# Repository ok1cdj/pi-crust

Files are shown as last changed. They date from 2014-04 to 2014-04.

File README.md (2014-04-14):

Pi Crust
========

This is a PCB that brings sanity to Raspberry Pi headers.

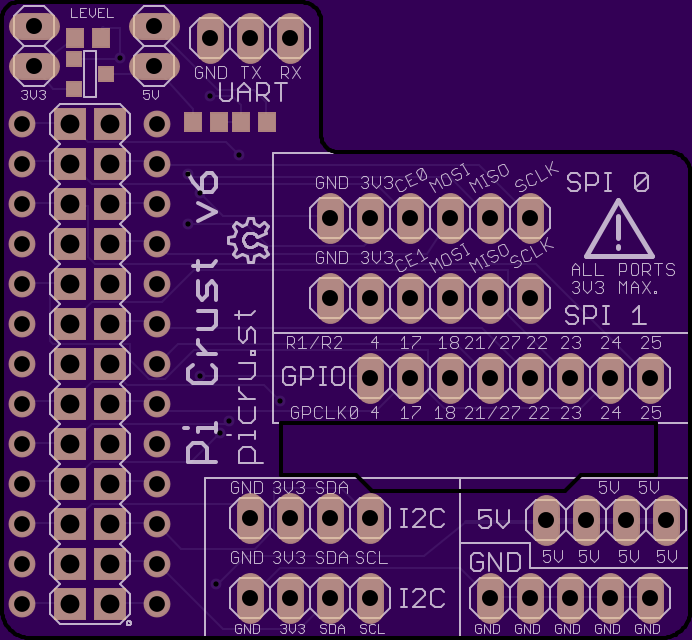
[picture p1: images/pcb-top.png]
Pi Crust PCB Layout


See [http://picru.st](http://picru.st) for more.

Features
--------

*   Really compact - sits *inside* the surface area of the Raspberry Pi and adds less than 2mm to the height. If you have a case for your Raspberry Pi, this board should fit inside it.
*   Pins are grouped together: GPIO, I2C, SPI, UART and power.
*   Every pin is clearly labelled added labels for RPi revision 1 and 2.
*   Connections: 2 x SPI, 2 x I2C, 1 x UART, 8 x GPIO
*   Added bidirectional 2 ports level converter
*   Uses female headers instead of male headers - you can poke jumpers right in.
*   Lots of GND and 5V pins - you need those guys a lot. These pins are duplicated where it makes sense (e.g. within the UART, I2C and SPI groups).
*   All thru-hole components - you can solder it yourself.
*   Cheapety cheapy cheap.
*   Open source hardware.
*   [More photos here](http://todayimade.co/items/joe-walnes-made-a-tiny-breakout-board-for-raspberry-pi)

See [http://picru.st](http://picru.st) for more.

Bitdeli Badge (https://bitdeli.com/free "Bitdeli Badge")

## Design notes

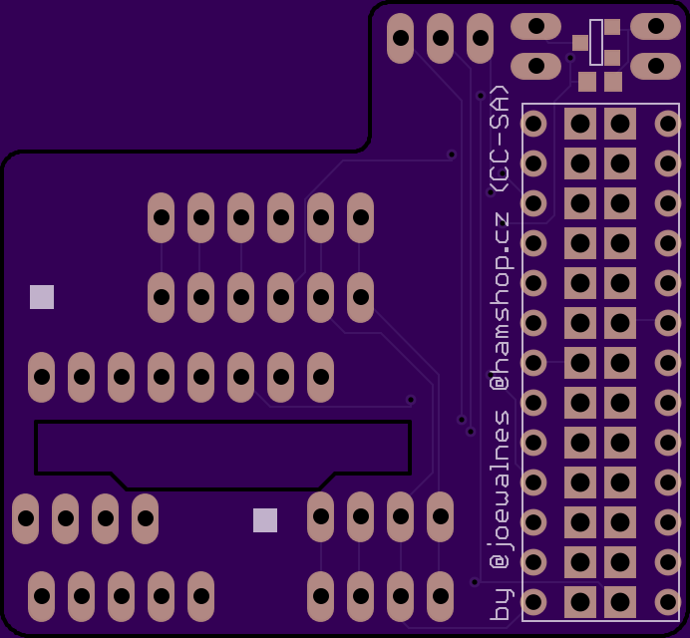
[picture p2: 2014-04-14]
images/pcb-bottom.png

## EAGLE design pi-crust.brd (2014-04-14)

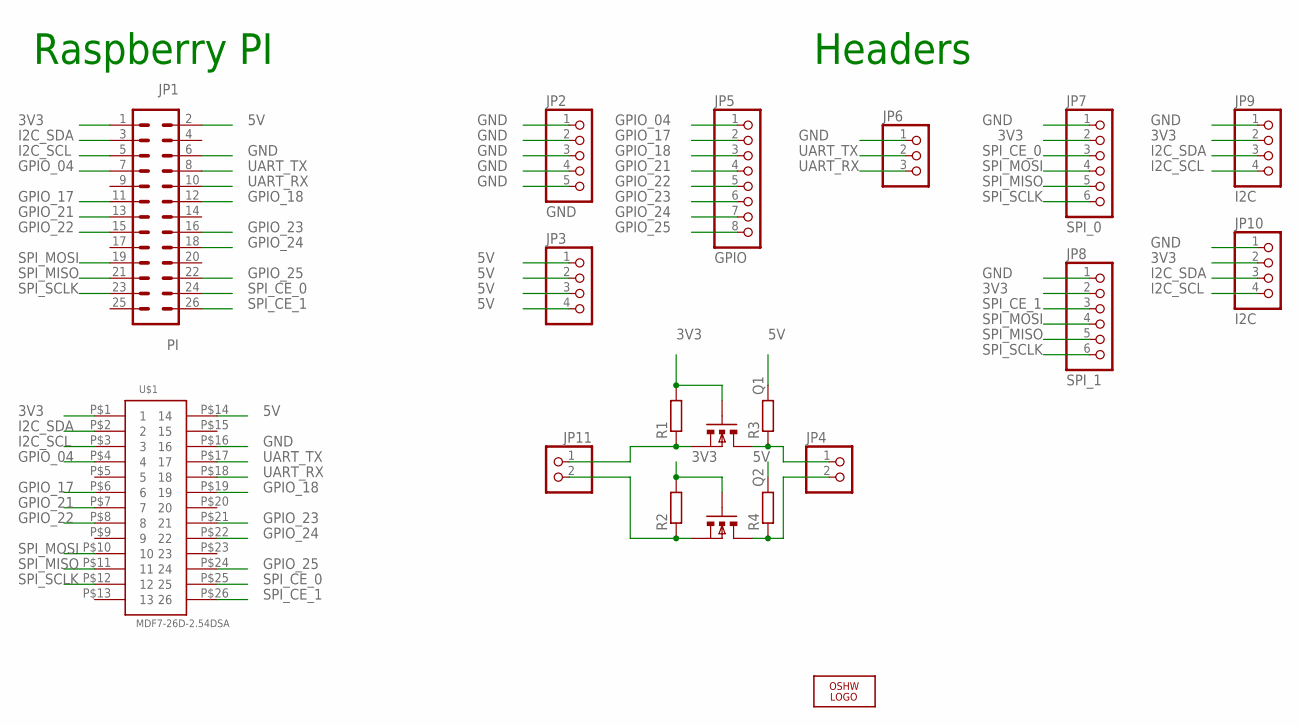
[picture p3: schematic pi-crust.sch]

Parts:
JP1: PI; MA13-2
JP2: GND; 1X05
JP3: PINHD-1X4; 1X04
JP4, JP11: PINHD-1X2; 1X02
JP5: GPIO; 1X08
JP6: PINHD-1X3; 1X03
JP7: SPI_0; 1X06
JP8: SPI_1; 1X06
JP9, JP10: I2C; 1X04
LOGO1: OSHW_LOGO_8MILX0100-NT; OSHW_8X100_NOTEXT
Q1, Q2: BSS138SMD; SOT23
R1, R2, R3, R4: R-EU_R0603; R0603
U$1: MDF7-26D-2.54DSA

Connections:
3V3: JP1.1, JP7.2, JP8.2, JP9.2, JP10.2, Q1.2 (G), Q2.2 (G), R1.2, R2.2, U$1.P$1 (1)
5V: JP1.2, JP3.1, JP3.2, JP3.3, JP3.4, R3.2, R4.2, U$1.P$14 (14)
GND: JP1.6, JP2.1, JP2.2, JP2.3, JP2.4, JP2.5, JP6.1, JP7.1, JP8.1, JP9.1, JP10.1, U$1.P$16 (16)
GPIO_04: JP1.7, JP5.1, U$1.P$4 (4)
GPIO_17: JP1.11, JP5.2, U$1.P$6 (6)
GPIO_18: JP1.12, JP5.3, U$1.P$19 (19)
GPIO_21: JP1.13, JP5.4, U$1.P$7 (7)
GPIO_22: JP1.15, JP5.5, U$1.P$8 (8)
GPIO_23: JP1.16, JP5.6, U$1.P$21 (21)
GPIO_24: JP1.18, JP5.7, U$1.P$22 (22)
GPIO_25: JP1.22, JP5.8, U$1.P$24 (24)
I2C_SCL: JP1.5, JP9.4, JP10.4, U$1.P$3 (3)
I2C_SDA: JP1.3, JP9.3, JP10.3, U$1.P$2 (2)
unnamed: JP11.2, Q2.1 (S), R2.1
unnamed: JP4.2, Q2.3 (D), R4.1
unnamed: JP11.1, Q1.1 (S), R1.1
unnamed: JP4.1, Q1.3 (D), R3.1
SPI_CE_0: JP1.24, JP7.3, U$1.P$25 (25)
SPI_CE_1: JP1.26, JP8.3, U$1.P$26 (26)
SPI_MISO: JP1.21, JP7.5, JP8.5, U$1.P$11 (11)
SPI_MOSI: JP1.19, JP7.4, JP8.4, U$1.P$10 (10)
SPI_SCLK: JP1.23, JP7.6, JP8.6, U$1.P$12 (12)
UART_RX: JP1.10, JP6.3, U$1.P$18 (18)
UART_TX: JP1.8, JP6.2, U$1.P$17 (17)

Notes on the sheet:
Raspberry PI
Headers

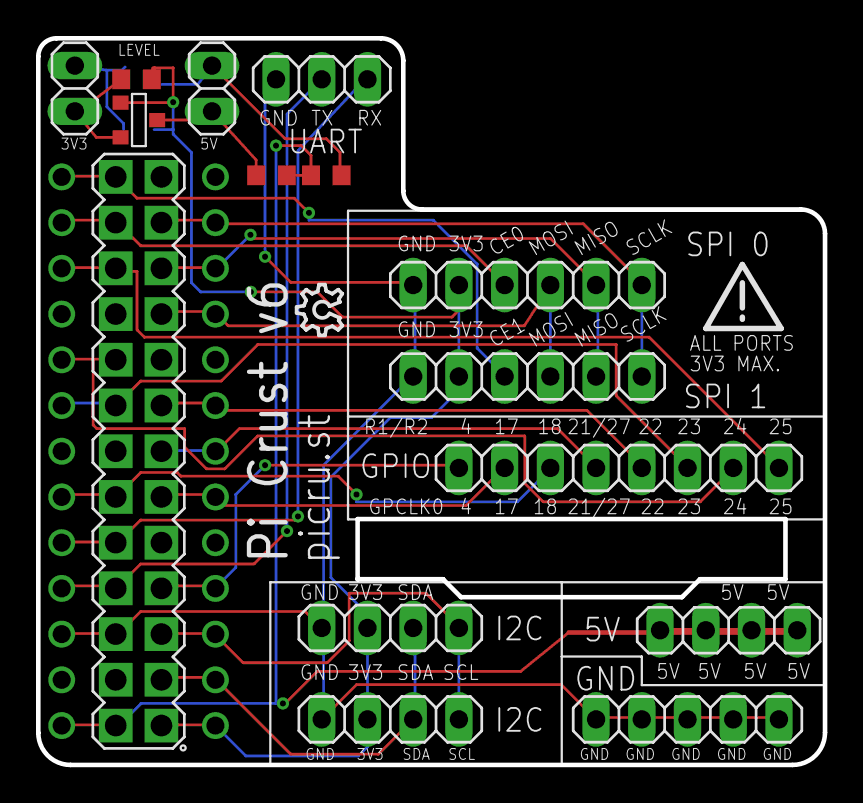
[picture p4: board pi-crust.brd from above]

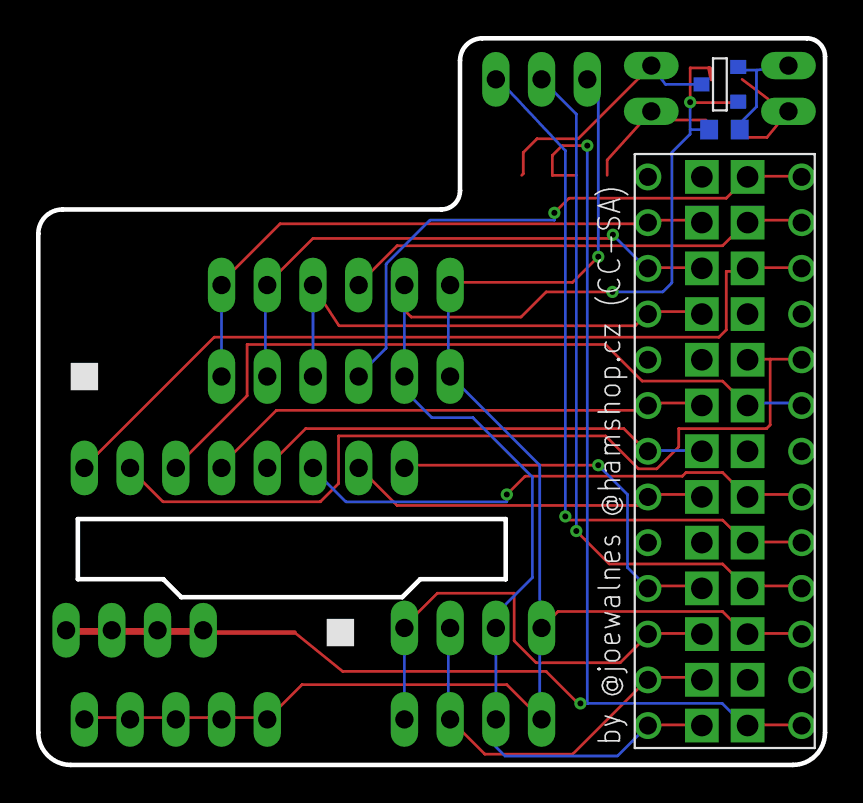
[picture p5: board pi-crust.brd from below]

Board: 2 copper layers, 43.7 x 40.4 mm, 19 parts (3 on the bottom side), 24 nets.

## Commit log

2014-04-13 Replaced 5V pins in ports to 3V3. Added 2 ports level converter for convert data lines from 3V3 to 5V. Updated labeling of pins for both revisions of RPi...
    [pi-crust.brd, pi-crust.sch]
2014-04-14 Minor changes..
    [pi-crust.brd]
2014-04-14 New images of PCB..
